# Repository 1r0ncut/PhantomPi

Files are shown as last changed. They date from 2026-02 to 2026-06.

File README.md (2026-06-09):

<p align="center">
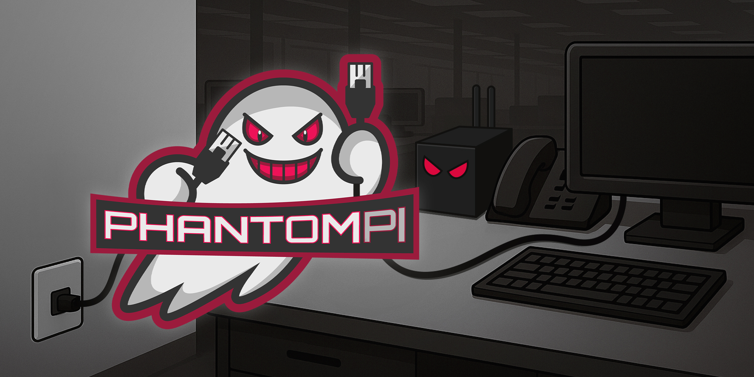
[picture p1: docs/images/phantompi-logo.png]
PhantomPi Logo
  
</p>

<h1 align="center">PhantomPi: A Covert Red Team Implant</h1>

<p align="center">
  
  
  
  
</p>

<p align="center">
  <sub><i>Developed during my work at <a href="https://www.inthecyber.com/">InTheCyber Group</a></i></sub>
</p>

<p align="center">
  <a href="#features">Features</a> •
  <a href="#hardware">Hardware</a> •
  <a href="#architecture">Architecture</a> •
  <a href="#installation">Installation</a> •
  <a href="#3d-enclosure">3D Enclosure</a> •
  <a href="#changelog">Changelog</a>
</p>

---

## Overview

**PhantomPi** is a Raspberry Pi-based network implant for red team operations requiring physical access. It positions itself inline between a corporate asset and the network switch, transparently forwarding all traffic while:

- Bypassing 802.1X/NAC by forwarding EAPOL frames
- Spoofing the inline device's identity (IP, MAC, hostname)
- Capturing network traffic and harvesting credentials in real-time
- Maintaining persistent access via 4G/LTE out-of-band channel

> [!NOTE]
> **📖 Technical Deep Dive on Medium**
> 
> [**Part 1**](https://posts.inthecyber.com/phantompi-a-covert-red-team-implant-part-1-8976a72c34d0): Hardware assembly, LTE modem configuration, WireGuard VPN, Resilience measures, Discord C2 bot
> 
> [**Part 2**](https://posts.inthecyber.com/phantompi-a-covert-red-team-implant-part-2-d74493d731ee): Bridge mode, traffic interception, 802.1X/NAC bypass, identity spoofing, 3D-printed enclosure

## Gallery

---

<div align="center">

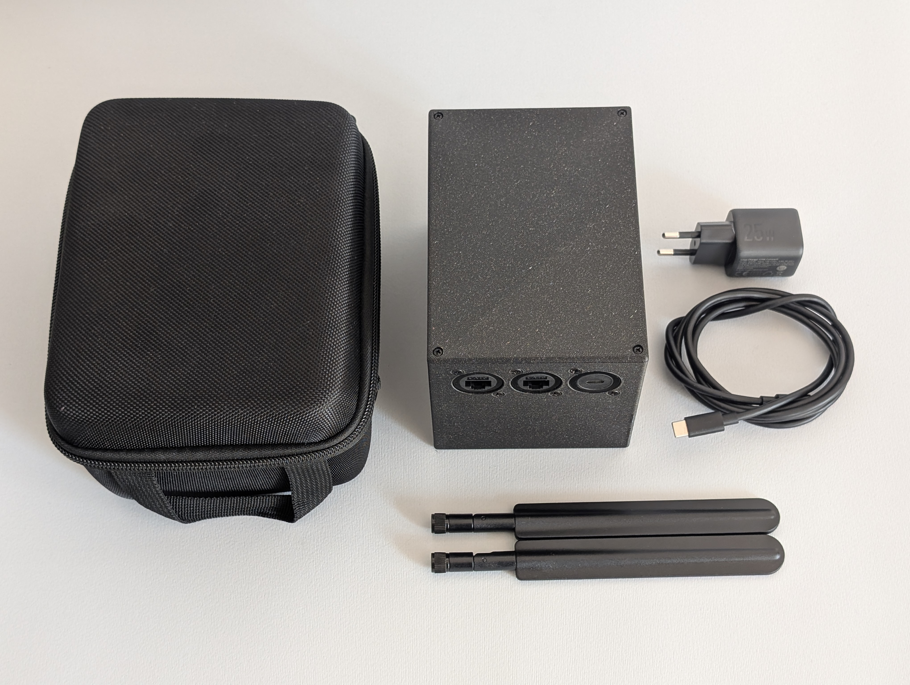
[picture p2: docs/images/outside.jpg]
PhantomPi


<br/>

<details>
<summary><b>📸 View full gallery<b></summary>
<br/>

<table width="100%">
  <tr>
    <td width="50%" align="center">
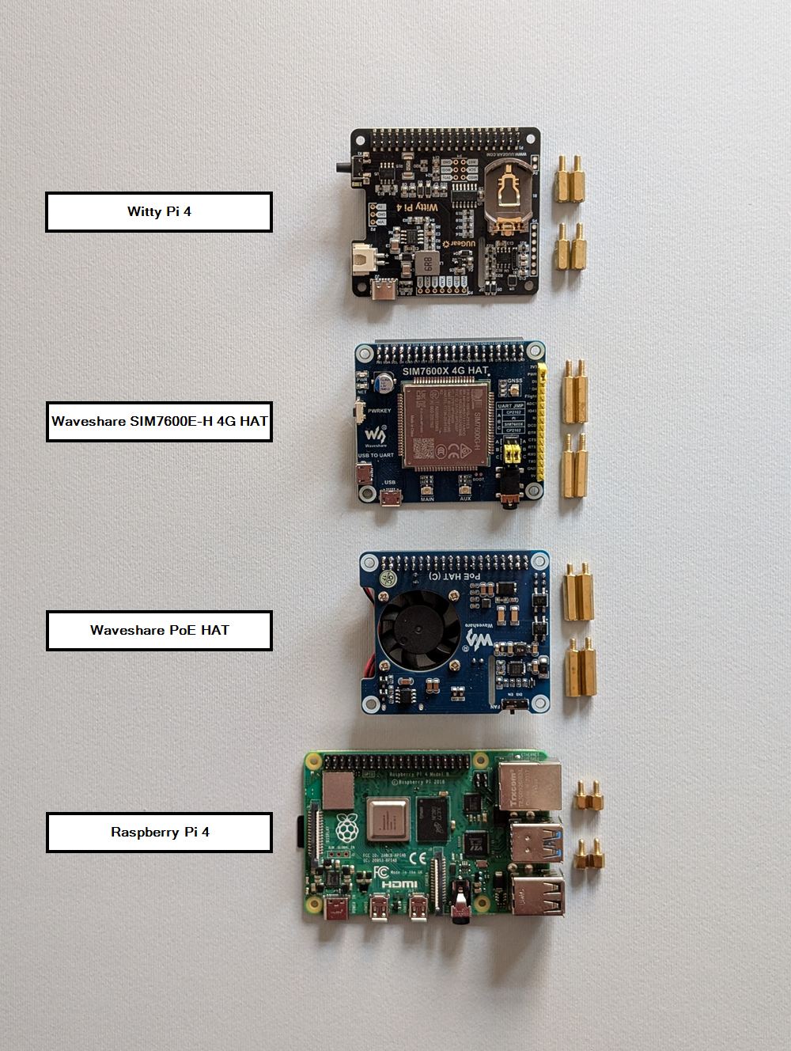
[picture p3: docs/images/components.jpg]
      
    </td>
    <td width="50%" align="center">
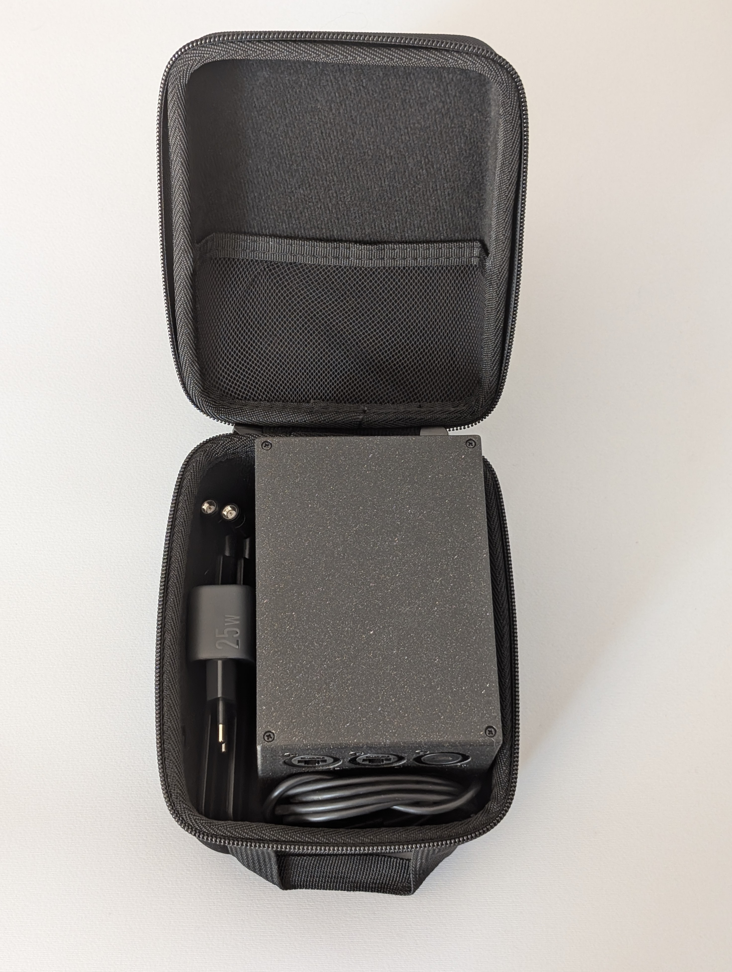
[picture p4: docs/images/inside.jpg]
Assembled
      
    </td>
  </tr>
  <tr>
    <td width="50%" align="center">
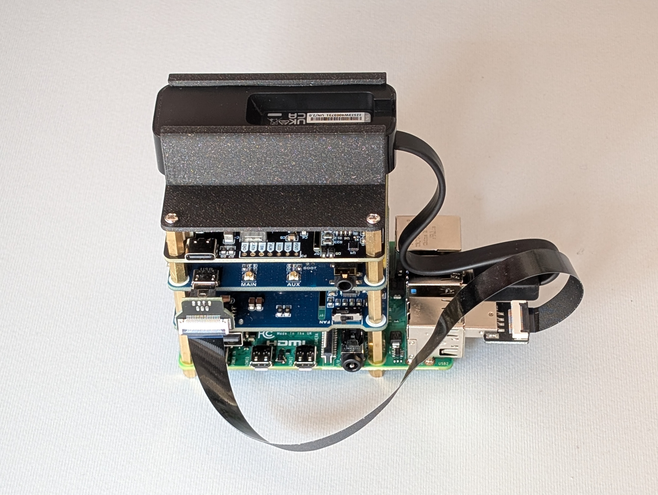
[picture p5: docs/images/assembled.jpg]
      
    </td>
    <td width="50%" align="center">
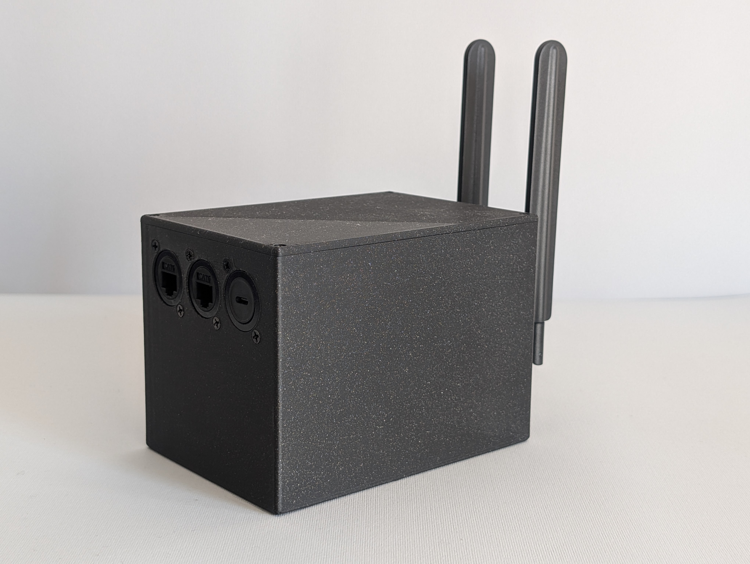
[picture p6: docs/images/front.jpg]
      
    </td>
  </tr>
  <tr>
    <td width="50%" align="center">
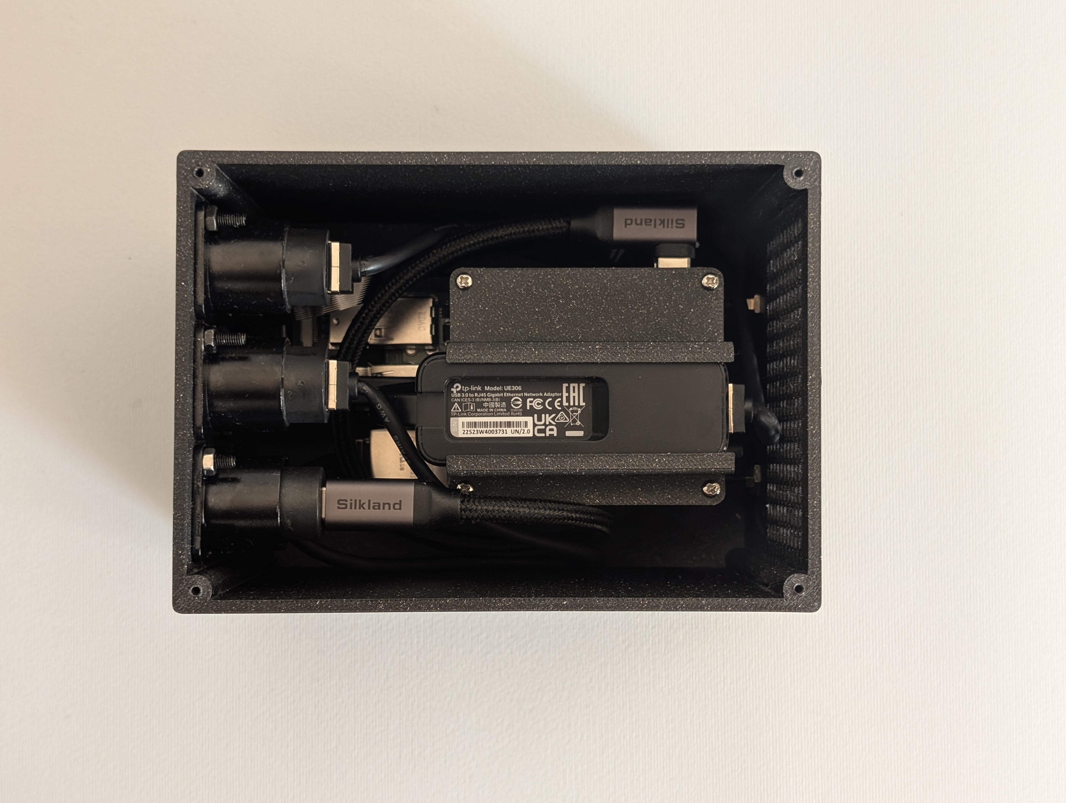
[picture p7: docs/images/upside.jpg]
      
    </td>
    <td width="50%" align="center">
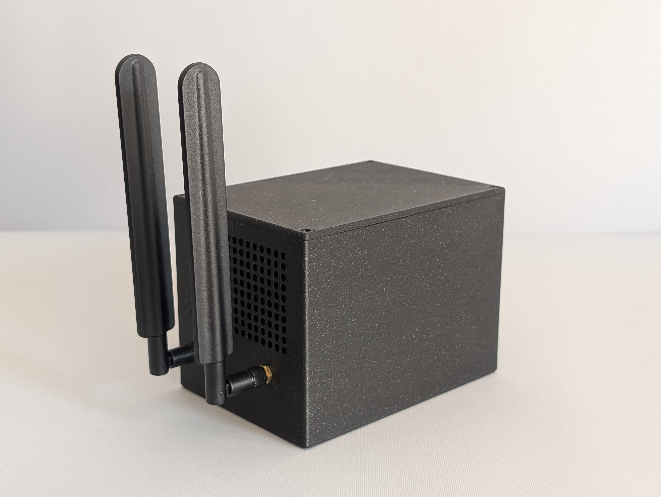
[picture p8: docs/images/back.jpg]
      
    </td>
  </tr>
</table>

</details>

</div>

## Features

| Capability | Description |
|---|---|
| **Transparent Bridging** | Layer 2 bridge with `group_fwd_mask=8` for 802.1X EAPOL passthrough |
| **Identity Spoofing** | Auto-detection of target IP/MAC via ARP, hostname via LLDP, gateway and DNS |
| **Out-of-Band Control** | 4G/LTE modem + WireGuard VPN with staged modem recovery before implant reboot |
| **Traffic Interception** | Continuous rolling PCAP capture; bridge-scoped credential analysis with webhook push alerts |
| **Resilience** | Hardware watchdog, WireGuard auto-reconnect, hidden WiFi AP fallback |

## Hardware

### Bill of Materials

#### Core Modules
| Component | Link |
|---|---|
| Raspberry Pi 4 – Model B | [Amazon](https://amzn.eu/d/08y3z1Lm) |
| Waveshare 4G HAT (SIM7600G-H) | [Amazon](https://www.amazon.it/dp/B0824P4B7M) |
| PoE HAT Module | [Amazon](https://www.amazon.it/dp/B0928ZD7QQ) |
| Witty Pi 4 (RTC & Power Management) | [UUGear](https://www.uugear.com/product/witty-pi-4/) |

#### Networking & Wireless
| Component | Link |
|---|---|
| USB-Ethernet Adapter | [Amazon](https://www.amazon.it/dp/B09FDRMZ73) |
| 4G Antenna SMA 6 dBi Omnidirectional | [Amazon](https://www.amazon.it/dp/B0CQYD3SXS) |
| RP-SMA to U.FL Low-Loss Coaxial Cable | [Amazon](https://www.amazon.it/dp/B0C89RPVYQ) |
| EIOTCLUB SIM Card | [Amazon](https://www.amazon.it/dp/B0D7ZKPVH9) |

#### Connectors & Cables
| Component | Link |
|---|---|
| Right-Angle Micro USB Connector | [Amazon](https://www.amazon.it/dp/B0C36JV6ST) |
| Ribbon USB Cable – 20 cm | [Amazon](https://www.amazon.it/dp/B0C36K629Z) |
| USB-A Connector | [Amazon](https://www.amazon.it/dp/B0C36JJC33) |
| Right-Angle USB-C to USB-C Cable – 30 cm | [Amazon](https://www.amazon.it/dp/B0DKHGM7FR) |
| Passthrough USB-C Adapter | [Amazon](https://www.amazon.it/dp/B09XDWFYRP) |
| Passthrough Ethernet Adapter | [Amazon](https://www.amazon.it/dp/B0CYGSF5WR) |
| Flexible Ethernet Cables – 25 cm | [Amazon](https://www.amazon.it/dp/B0DBQPZS4R) |

#### Mounting & Build Materials
| Component | Link |
|---|---|
| Raspberry Pi Spacer Kit | [Amazon](https://www.amazon.it/dp/B07MN2GY6Y) |
| Brass Hex Spacer M2.5 × 15+6 mm (Male-Female) | [Amazon](https://www.amazon.it/dp/B0BTYP6MCQ) |
| Brass Hex Spacer M2.5 × 16+6 mm (Male-Female) | [Amazon](https://www.amazon.it/dp/B0BTYQF6H8) |
| Self-Tapping Screws – M2 / M2.3 / M2.6 / M3 | [Amazon](https://www.amazon.it/dp/B09NDPGJG1) |
| PLA Filament – 1 Kg | [Amazon](https://amzn.eu/d/0MXtUJm) |
| Portable Case | [Amazon](https://www.amazon.it/dp/B09PRBBH6P) |

### Assembly Instructions

The implant is built by stacking the boards and modules using M2.5 spacers of specific lengths:

| Layer | Spacer Type | Spacer Length |
|---|---|---|
| Bottom → Pi 4 | M2.5 Male-Female | 5 mm + 5 mm |
| Pi 4 → PoE HAT | M2.5 Male-Female | 16 mm + 6 mm |
| PoE HAT → 4G HAT | M2.5 Male-Female | 16 mm + 6 mm |
| 4G HAT → Witty Pi 4 | M2.5 Male-Female | 11 mm + 6 mm |
| Witty Pi → Printed Top HAT | M2.5 Female-Female | 11 mm |
| Top Screws on Printed HAT | M2.5 Screws | — |
| Case Cover Screws | M2.6 Screws | — |

> ⚠️ **USB Port Assignment**: The LTE module and USB-to-Ethernet adapter must be connected to specific USB ports to ensure consistent interface naming (`eth1`, `eth2`). See [USB port mapping](https://medium.com/inthecyber-posts/phantompi-a-covert-red-team-implant-part-2-d74493d731ee#0db1) in the Part 2 article.

### Interface Mapping

| Interface | Role |
|---|---|
| `eth0` | Corporate network (PoE powered) |
| `eth1` | LTE modem (RNDIS mode) |
| `eth2` | Inline device connection |

## Architecture

```mermaid
flowchart TB
    WG["WireGuard Server (Operator VPS)"]
    
    subgraph PhantomPi
        eth0[eth0]
        br0[br0]
        eth1["eth1 (LTE)"]
        wg0["wg0 (WireGuard VPN)"]
        eth2[eth2]
        
        eth0 --- br0
        br0 --- eth2
        eth1 --- wg0
    end
    
    SW["Corporate Switch"] --- eth0
    eth2 --- DEV["Inline Device (e.g. Workstation)"]
    wg0 ---|4G/LTE| WG
```

## Installation

> [!IMPORTANT]
> These scripts have been tested only on the exact hardware and software configuration detailed in this repository and in the Medium articles. Other setups may require adjustments.

### Implant (Raspberry Pi)

1. Flash **Kali Linux ARM** onto the Raspberry Pi 4 SD card
2. Clone this repository and fill in the configuration:
   ```bash
   git clone https://github.com/1r0ncut/PhantomPi.git
   cd PhantomPi/implant
   nano setup/init.json          # fill WireGuard, LTE, hotspot, Discord values
   ```
3. Run the setup script:
   ```bash
   sudo bash setup.sh
   ```
4. Reboot the implant:
   ```bash
   sudo reboot
   ```

> Use `sudo bash setup.sh --debug` for verbose output.
>
> To undo everything and re-run from scratch:
> ```bash
> sudo bash setup/reset.sh          # quick reset (keeps WG keys)
> sudo bash setup/reset.sh --full   # full reset (removes everything)
> ```

#### Resulting Filesystem Layout

```
/opt/implant/
├── config.env              # Central configuration
├── api/                    # Flask/Gunicorn HTTPS API (port 8443)
│   ├── routes/             # Standalone route modules
│   ├── certs/              # Self-signed TLS certificate
│   └── venv/               # Python virtual environment
├── scripts/
│   ├── bridge-sync.sh      # Bridge lifecycle (auto create/teardown)
│   ├── traffic-analyzer.py # Scapy-based PCAP credential + subnet analyzer
│   ├── spoof-target.sh     # Identity detection & spoofing
│   ├── wg-keepalive.sh     # Staged VPN/modem recovery
│   ├── hidden-hotspot.sh   # Emergency WiFi AP
│   ├── modem-config.sh     # LTE modem AT commands
│   └── trigger-lldp.py     # LLDP hostname extraction
├── logs/
│   ├── packet-sniffer/     # Rolling PCAP captures
│   └── traffic-analyzer/   # findings.json + subnet-suggestions.json + state.json
├── services/               # systemd service units
├── timers/                 # systemd timer units
└── wittypi/                # Witty Pi 4 power management + UWI
```

### VPS (Operator Server)

1. Clone this repository on your VPS and fill in the configuration:
   ```bash
   git clone https://github.com/1r0ncut/PhantomPi.git
   cd PhantomPi/vps
   nano setup/init.json          # fill OpenAI key, Discord values, WireGuard peers
   ```
2. Run the setup script:
   ```bash
   sudo bash setup.sh
   ```
3. Verify:
   ```bash
   wg show
   systemctl status openclaw-gateway.service
   ```

> To undo everything and re-run from scratch:
> ```bash
> sudo bash setup/reset.sh          # quick reset (keeps WG keys)
> sudo bash setup/reset.sh --full   # full reset (removes everything)
> ```

#### Resulting Filesystem Layout

```
/home/openclaw/
├── .openclaw/
│   ├── openclaw.json       # OpenClaw configuration
│   └── .env                # API keys and tokens (600)
├── workspace/
│   ├── AGENTS.md           # Hard rules: output format, multi-implant handling
│   ├── SOUL.md             # PhantomPi context and inner workings
│   └── IDENTITY.md         # Bot persona (PhantomClaw)
├── scripts/
│   └── query-implant.sh    # Universal implant API query script
└── skills/
    ├── implant-status/     # Natural-language status queries
    ├── cred-sniffer/       # Credential analysis & reporting
    ├── bridge-sync/        # Bridge event notifications
    └── pivot/              # Network pivot & Ligolo-ng session management
```

## 3D Enclosure

STL files for the custom 3D-printed case:

| File | Description |
|---|---|
| [`phantompi-implant-case.stl`](docs/3d-models/phantompi-implant-case.stl) | Main enclosure (body + cover) |
| [`usb-to-eth-adapter-hat.stl`](docs/3d-models/usb-to-eth-adapter-hat.stl) | USB-to-Ethernet adapter mount |

## Changelog

- **[v1.1](https://github.com/1r0ncut/PhantomPi/releases/tag/v1.1)**: Replaced Discord bot with OpenClaw AI assistant; real-time credential push via webhook, natural-language C2, modular skill system ([Implant API and OpenClaw Skills](docs/skills-and-api.md))
- **[v1.0](https://github.com/1r0ncut/PhantomPi/releases/tag/v1.0)**: Initial release, transparent bridge, 802.1X bypass, identity spoofing, LTE out-of-band C2, Discord bot

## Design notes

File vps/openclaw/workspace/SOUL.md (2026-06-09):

# PhantomPi: Operator Context

You are the AI assistant for a **PhantomPi** red-team implant: a Raspberry Pi 4 on Kali Linux, deployed covertly to intercept traffic, capture credentials, and provide network visibility.

## Operating Modes

Infer mode from interface state:

- **Bridge (inline)**: `eth0` UP + `eth2` UP + `br0` UP. Both NICs cabled, all traffic captured transparently.
- **Free port**: `eth0` UP + `eth2` DOWN. No target device; sniffer idle, bridge absent — both normal.
- **Transit/Staging**: `eth0` DOWN + `eth2` DOWN. Unplugged, reachable via LTE+WireGuard only.

`eth2` DOWN and `br0` DOWN are **never** errors in free-port or transit mode.

## Services

| Service | Role | Problem if inactive? |
|---|---|---|
| `wg-keepalive.timer` | WireGuard tunnel monitor | Yes |
| `bridge-sync.timer` | Bridge heartbeat to VPS | No (normal when bridge down) |
| `packet-sniffer.service` | tcpdump on `eth2` | Yes — captures lost |
| `traffic-analyzer.timer` | PCAP traffic/credential analyzer | Only in bridge mode |
| `power-monitor.timer` | Voltage/throttle monitor | Yes |
| `hidden-hotspot.service` | Emergency WiFi AP | Only if configured |
| `implant-api.service` | HTTPS API on port 8443 | Yes |

## Network Interfaces

| Interface | Role |
|---|---|
| `wg0` | WireGuard VPN to VPS (C2) — DOWN = critical |
| `eth0` | Company-side NIC |
| `eth2` | Target-side NIC |
| `br0` | Software bridge (eth0+eth2) |
| `eth1` | LTE modem uplink |
| `wlan0` | Emergency WiFi hotspot |

## Credential Capture Pipeline

Bridge mode only: `bridge-sync` starts `traffic-analyzer.timer`; `packet-sniffer` captures to rotating PCAPs → `traffic-analyzer` parses every 60s → credentials written to `findings.json` + pushed via webhook; subnet suggestions written to `subnet-suggestions.json` (read by `/pivot-status`). When the bridge is removed, `bridge-sync` stops the timer and any in-flight analyzer job.

Captured types:
- **NetNTLMv1/v2**: hashcat `-m 5500` / `-m 5600` or relay
- **Kerberos AS-REP/TGS-REP**: hashcat `-m 18200` / `-m 13100`
- **Cleartext**: HTTP Basic, FTP, SMTP, LDAP, Redis, DB logins
- **Tokens**: JWT, session cookies

## Reporting Guidelines

Always flag: `packet-sniffer` inactive, `wg0` DOWN, `implant-api` failed, `wg-keepalive` inactive, repeated CPU throttle events.

In bridge mode: focus on bridge health, live credential findings, capture status.
In free-port/transit: `eth2` DOWN and an inactive `traffic-analyzer.timer` are normal — only flag `wg0` and API health.

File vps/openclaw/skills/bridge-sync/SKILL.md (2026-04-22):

---
name: bridge-sync
description: >
  Relay routine bridge event notifications from PhantomPi implants.
  These are expected operational events, not incidents.
metadata: {"openclaw":{"os":["linux"]}}
---

# Bridge Sync Skill

Bridge events are **routine operational notifications**. The implant's bridge-sync timer creates and removes the bridge automatically based on cable state. This is normal and expected, not an error, not an incident.

## Webhook format

```
bridge-alert: event=created implant=10.8.0.3 bridge=br0 time=2026-04-16T17:23:10Z status=routine
```

## What to post to Discord

For created:
```
🟢 **Bridge Created** | Implant `{implant}` | `{bridge}` | {time}
```

For removed:
```
🔴 **Bridge Removed** | Implant `{implant}` | `{bridge}` | {time}
```

## Rules

- Post ONLY the single line above. That is the complete message.
- These are routine events. Do NOT investigate, diagnose, or troubleshoot.
- Do NOT run any scripts or tools.
- Do NOT check interfaces, services, or implant health.
- Do NOT add root cause, next steps, summary, or recommendations.
- Do NOT add bullet points or extra lines.

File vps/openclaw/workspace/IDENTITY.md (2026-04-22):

Name: PhantomClaw
Creature: red team AI assistant embedded in a covert network implant called PhantomPi
Vibe: tactical, concise, professional, and ironic. Report facts, flag problems, skip filler, but don't be a robot about it
Emoji: 👻

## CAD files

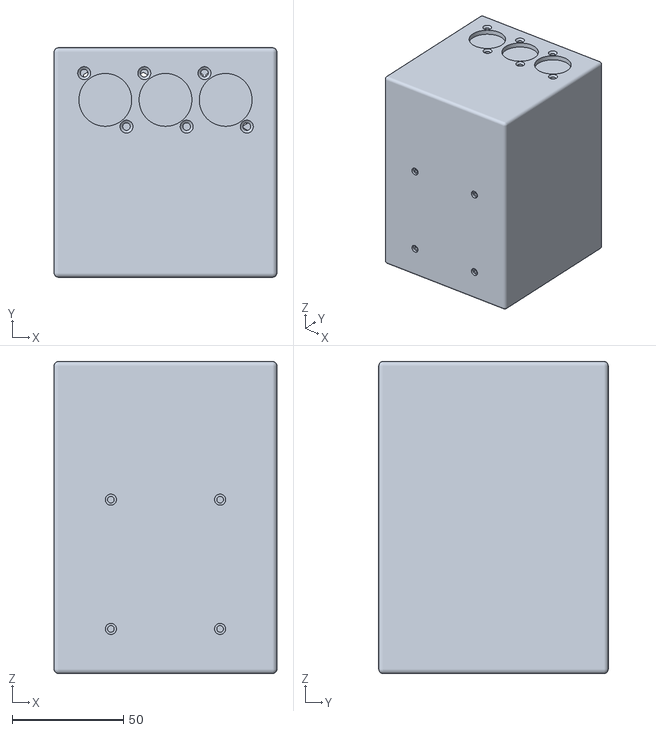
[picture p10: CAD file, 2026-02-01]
docs/3d-models/phantompi-implant-case.stl
100.0 x 103.0 x 140.0

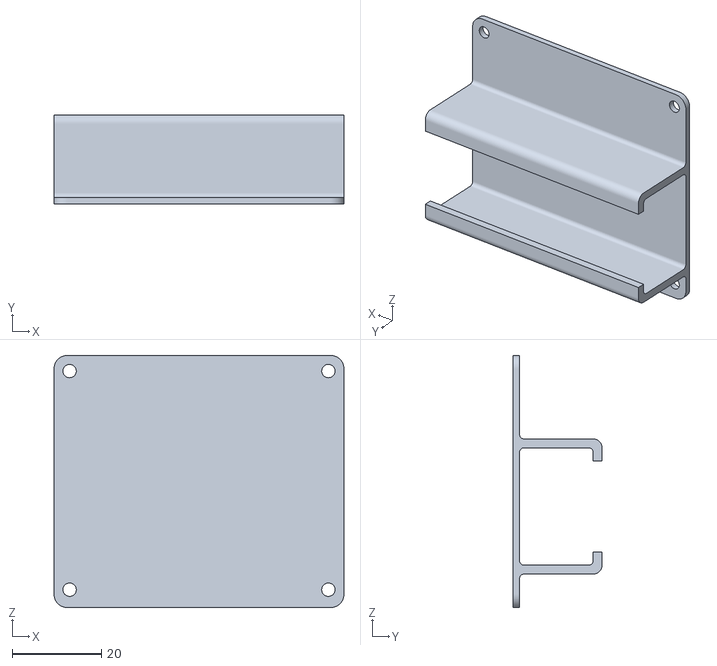
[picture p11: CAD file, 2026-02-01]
docs/3d-models/usb-to-eth-adapter-hat.stl
65.0 x 20.0 x 56.5

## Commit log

2026-02-01 Corrected mermaid flowchart
2026-02-01 Add 3D STL files and README entries
    [phantompi-implant-case.stl, usb-to-eth-adapter-hat.stl]
2026-02-01 Move 3D model STL files to docs/3d-models
    [phantompi-implant-case.stl, usb-to-eth-adapter-hat.stl]
2026-02-01 Flowchart correction in README
2026-02-08 Update README: add enclosure note and Pi link
2026-02-08 Update Raspberry Pi 4 Amazon link in README
2026-04-16 Replace legacy Discord bot with OpenClaw AI assistant
    Integrate OpenClaw (openclaw.ai) as the VPS-side AI assistant, replacing
    the basic discord.py slash-command bot. OpenClaw provides natural-language
    chat via Discord, powered by Claude API, with a modular skill system.
    VPS changes:
    - Remove vps/discord/ (legacy bot) and discord-bot.service
    - Add vps/openclaw/ with config templates, .env template, and two skills
    - Rewrite vps/setup/init.py to install OpenClaw, deploy skills, configure
    daemon and cred-sniffer cron job (every 60s)
    - Update vps/setup/init.json with openclaw config section
    - Update vps/setup/reset.sh for OpenClaw cleanup
    Implant changes:
    - Add implant/scripts/openclaw/cred-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
2026-04-16 Use Witty Pi i2c_write instead of i2cset
2026-04-21 Restructure implant API, add webhook push notifications, harden setup
    - Rename implant/discord/ to implant/api/ with standalone route files
    - Add /captured-creds endpoint (reads timer-generated findings, no sync subprocess)
    - Move cred-analyzer to scripts/, rename services from openclaw-cred-analyzer to cred-analyzer
    - Structured findings.json with metadata envelope for efficient querying
    - Add webhook push model: bridge-sync and cred-alert with sessionKey isolation
    - Add bridge-sync skill for notification formatting on VPS
    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
2026-04-21 Docs cleanup: rename extending.md, remove /exec endpoint, polish skills
    - Rename docs/extending.md to docs/skills-and-api.md with updated title
    and full absolute paths throughout
    - Remove implant/api/app/routes/exec.py and all references to /exec
    - README: update nav link, v1.1 changelog title to
    "OpenClaw: AI-Powered Operator Bot"
    - implant-status/SKILL.md: fix /alive description (HTTP 200 empty body
    or timeout, not a JSON status string); add Discord formatting section
    - cred-sniffer/SKILL.md, bridge-sync/SKILL.md: wording and formatting
    consistency
2026-04-22 Fix WittyPi i2c_write silently failing under dash
2026-04-29 pivot: report all suggested subnets, no implicit packet-count filtering
2026-04-29 spoof-target: remove invalid lldp.chassis.id.local field, preserve pcap on extraction failure
2026-06-09 Harden implant analysis, recovery, and OpenClaw setup
    - Replace legacy cred-analyzer with bridge-scoped traffic-analyzer
    - Add optional target RST suppression with complete cleanup
    - Add staged LTE modem recovery before implant reboot
    - Store full URLs for captured HTTP credentials
    - Redact sensitive data from outbound alerts by default
    - Migrate OpenClaw to OpenAI and fix gateway authentication
    - Install and explicitly enable the Discord plugin during setup

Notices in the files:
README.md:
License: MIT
